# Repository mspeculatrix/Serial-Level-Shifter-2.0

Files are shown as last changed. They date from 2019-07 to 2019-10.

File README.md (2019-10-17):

# Serial level shifter

This was always intended just as a daughterboard for my SmartParallel serial-to-parrallel printer interface card. It translates the 5V logic levels on the SmartParallel to 3.3V signals more suited for devices such as the Raspberry Pi.

**However**, experiments have shown that the TXB0104 chip used to do the level shifting can have severely limited power when it comes to driving the signal lines. As a result, this board might have very restricted applications.

Main description and explanation of the board:  https://mansfield-devine.com/speculatrix/2019/06/ttl-serial-level-shifter/
Details of problems encountered: https://mansfield-devine.com/speculatrix/2019/07/smartparallel-serial-shifter-issues/

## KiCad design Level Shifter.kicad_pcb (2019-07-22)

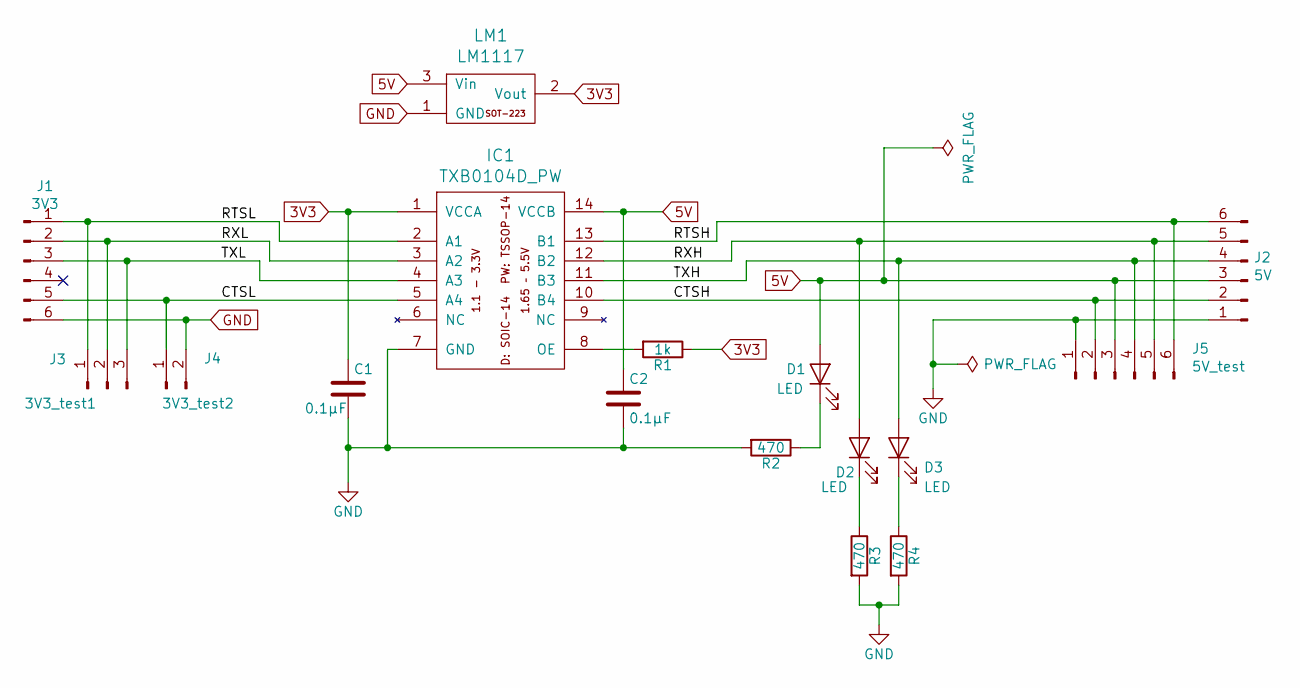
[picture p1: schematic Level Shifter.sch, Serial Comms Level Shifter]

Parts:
C1, C2: 0.1µF; C_1206
D1, D2, D3: LED; LED_1206
IC1: TXB0104D_PW; SOIC-14_3.9x8.7mm_Pitch1.27mm
J1: 3V3; Pin_Header_Straight_1x06
J2: 5V; Pin_Header_Straight_1x06
J3: 3V3_test1; Pin_Header_Straight_1x03
J4: 3V3_test2; Pin_Header_Straight_1x02
J5: 5V_test; Pin_Header_Straight_1x06
LM1: LM1117; SOT-223
R1: 1k; R_1206
R2, R3, R4: 470; R_1206

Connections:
3V3: C1.1, IC1.1 (VCCA), LM1.2 (Vout), R1.1
5V: C2.1, D1.2 (A), IC1.14 (VCCB), J2.3, J5.3, LM1.3 (Vin)
/CTSH: IC1.10 (B4), J2.2, J5.2
/CTSL: IC1.5 (A4), J1.5, J4.1
/RTSH: IC1.13 (B1), J2.6, J5.6
/RTSL: IC1.2 (A1), J1.1, J3.1
/RXH: D2.2 (A), IC1.12 (B2), J2.5, J5.5
/RXL: IC1.3 (A2), J1.2, J3.2
/TXH: D3.2 (A), IC1.11 (B3), J2.4, J5.4
/TXL: IC1.4 (A3), J1.3, J3.3
GND: C1.2, C2.2, IC1.7 (GND), J1.6, J2.1, J4.2, J5.1, LM1.1 (GND), R2.2, R3.2, R4.2
unnamed: D1.1 (K), R2.1
unnamed: D2.1 (K), R3.1
unnamed: D3.1 (K), R4.1
unnamed: IC1.8 (OE), R1.2

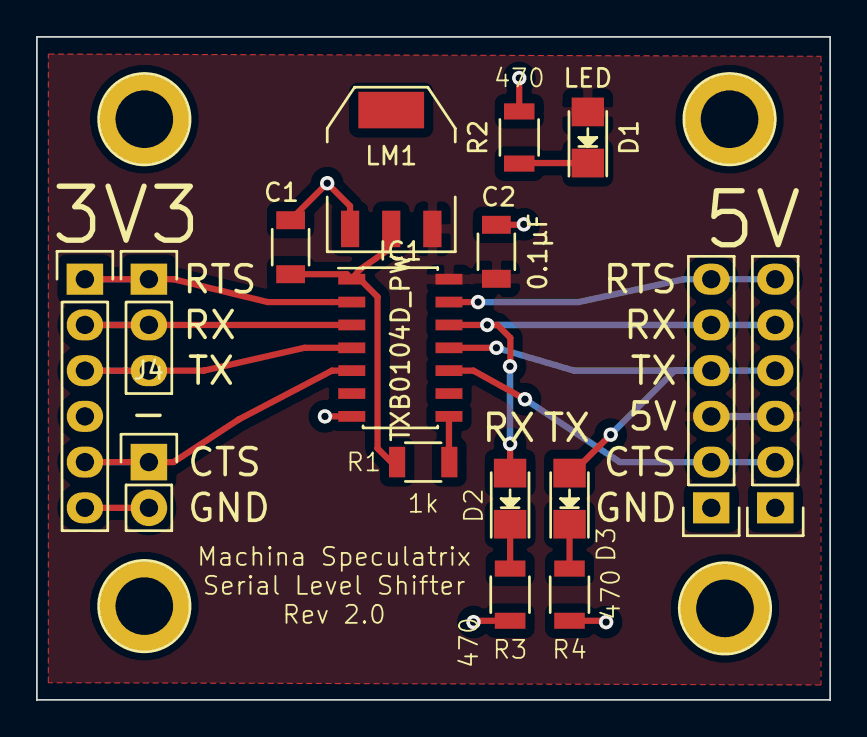
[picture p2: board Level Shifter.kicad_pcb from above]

Board: 2 copper layers, 44.1 x 36.8 mm, 16 parts (0 on the bottom side), 15 nets.

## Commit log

2019-06-18 Gerbers tidied up
    [Level Shifter-B.Cu.gbr, Level Shifter-B.Mask.gbr, Level Shifter-B.SilkS.gbr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]
2019-07-22 Revised with fixes
    [Level Shifter-B_Cu.gbr, Level Shifter-B_Mask.gbr, Level Shifter-B_SilkS.gbr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]
